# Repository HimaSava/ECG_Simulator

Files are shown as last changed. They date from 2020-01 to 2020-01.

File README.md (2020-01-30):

# ECG_Simulator

This project was part of my Winter Internship 2018 at Streben Healthcare Pvt. Ltd.

### Objective
To create an bluetooth enabled ECG simulator that can mimic the existing system and can trasfer the data without the need for an human subject to be connected to it.

The system should be compact and can replace the existing ECG simulators that are bulky and a hassel to carry around as well as to connect with the software physically.

### A bit about the system:
This ECG simulator was made to mimic the ECG data input from an standard ECG machine. And so the communication protocol is being followed as per the standard. 

Other than that this project is a basic Bluetooth enabled Arduino shield project. The multiple ECG datas are stored on the Arduino and the user can choose between them from the on the board switchs. 

The whole system is conpact and can be easily use a standard mobile powerbank as a power source making it very trasportable.

#### This project was coded and executed by using the following softwares:
* CodeBlocks (C++)
* Arduino IDE (C++)
* Termite (Serial Debugging)
* Eagle 7.6.0 (PCB Designing)

### Contents of the Repository
1. A complete PCB Design with the gerber files aready created.
2. A small C++ application to run on the computer for debugging the data transfer from the Device using bluetooth or USB.
3. The final Arduino code with the preprogrammed ECG Data.
4. Few images of the schematic and final board and PCB Designs.
5. A final Internship Report for the Project.

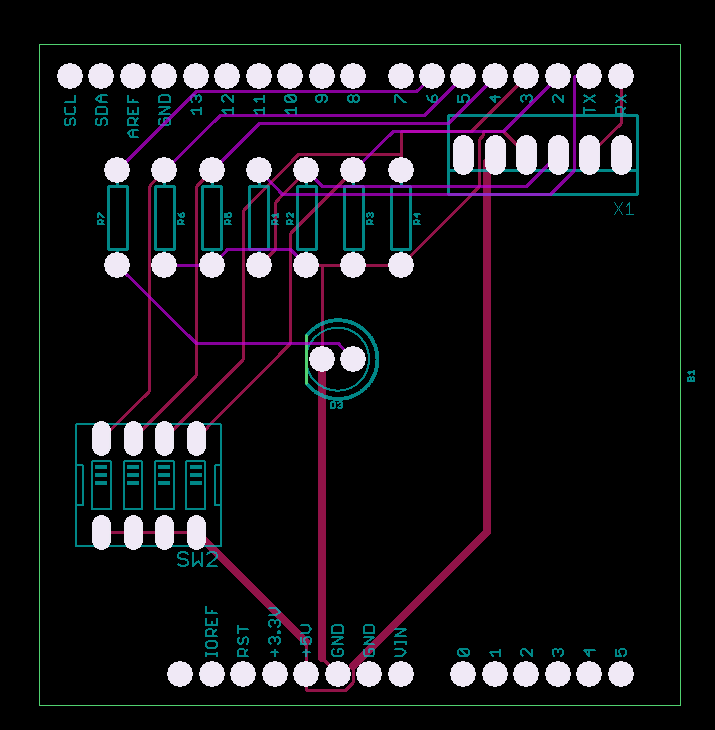
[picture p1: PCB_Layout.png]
PCB Layout


Final Device

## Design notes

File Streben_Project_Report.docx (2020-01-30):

ECG SIMULATOR

PROJECT REPORT

FOR- STREBEN HEALTHCARE PVT. LTD.

BY- HIMANSHU SAVARGAONKAR

INTRODUCTION

ECG(Electro-CardioGram) is one of the most vital measurement techniques when it comes to quantizing the health. It is used in many cases ranging from diagnosing heart diseases, critical surgeries to detecting of stress levels. Though ECG is one of the primary tools acquiring ECG data from a patent is a painstaking process, in which the patient has to be connected with 10 connectors on various parts of the body. These are then connected with the device to acquire the graph. This is very uncomfortable for testing reasons and for demonstrations. Thus, normally the human is replaced by an ECG Simulator for demonstration and development. The simulator is designed in a manner that mimics the human data helping software developers test their applications without physically connecting the leads to a human. Another advantage of a simulator is that the incoming ECG signal can be changed to different types as desired by the user, along with this it is normally quite compact and easy to store. ECG simulators are also used for the endurance test of software’s were the program runs for a long time at a time.

OBJECTIVES

- Development of an ECG simulator which is compatible with the current software.
- The ECG should be wireless and should be able to connect to the software via bluetooth connection.
- The device should give the user option to select from the various sample ECG’s stored on the device.
- The device should be concise with independent battery for easy transport.

SYTEM DESIGN /BLOCK DIAGRAM

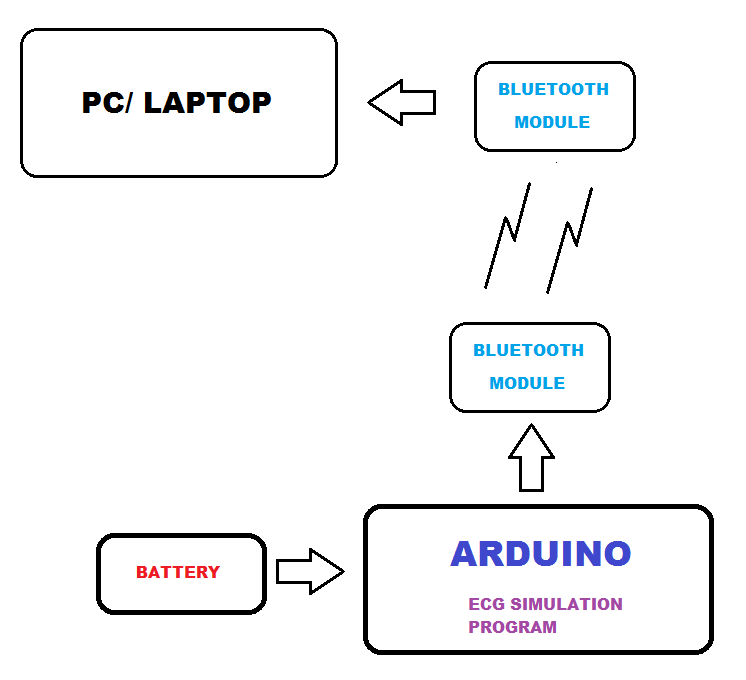
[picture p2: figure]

HARDWARE SUB SYSTEM

The project is based around main two hardware components. Arduino Uno microcontroller board and a HC-05 bluetooth module. The Uno board with AT Mega microcontroller houses the main code and the data of the ECG wave form. It is also responsible for proper compression and packetization of the data. The packetized data then is sent to the bluetooth module via SESRIAL COMMUNICARION PORT WITH Rx and Tx USING RS232 PROTOCOL. The bluetooth module then is connected to the computer running the software where it receives the data.

The device was provided with a dip switch which lets the user manually decide the ECG waveform from the multiple options on board. The device was also given a separate power-bank connection which made the independent AND PORTABLE. An on-board LED was added for visualization of the heart rate of the simulated patient.

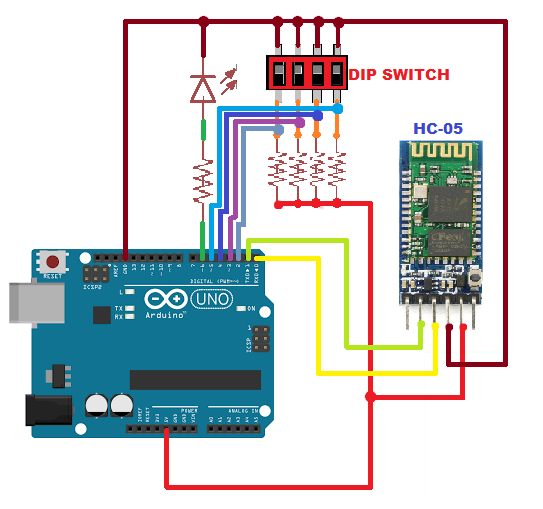
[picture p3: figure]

CIRCUIT DIAGRAM

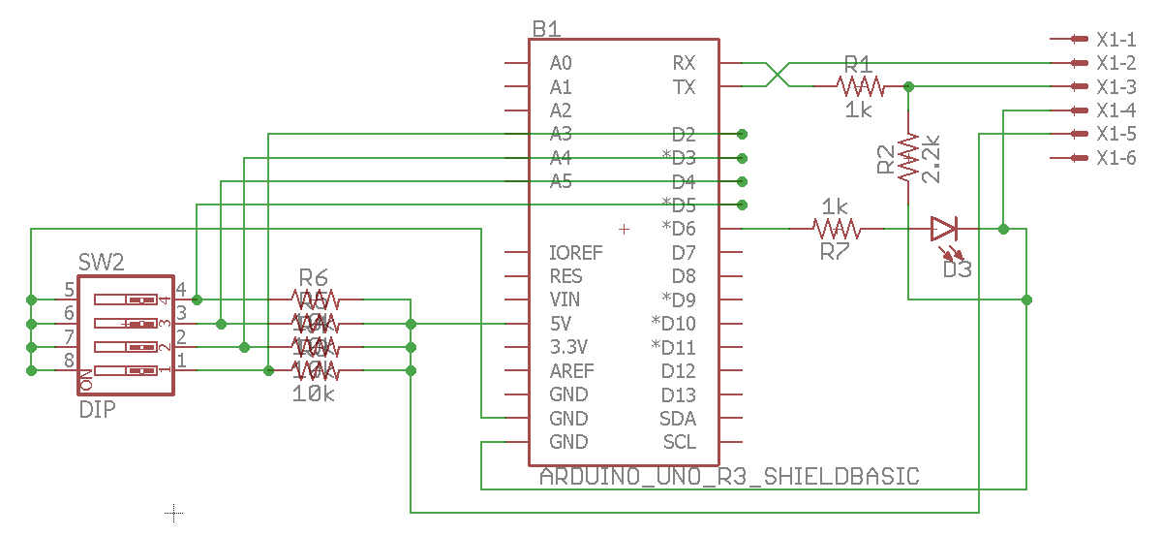
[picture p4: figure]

PCB SCHEMATIC

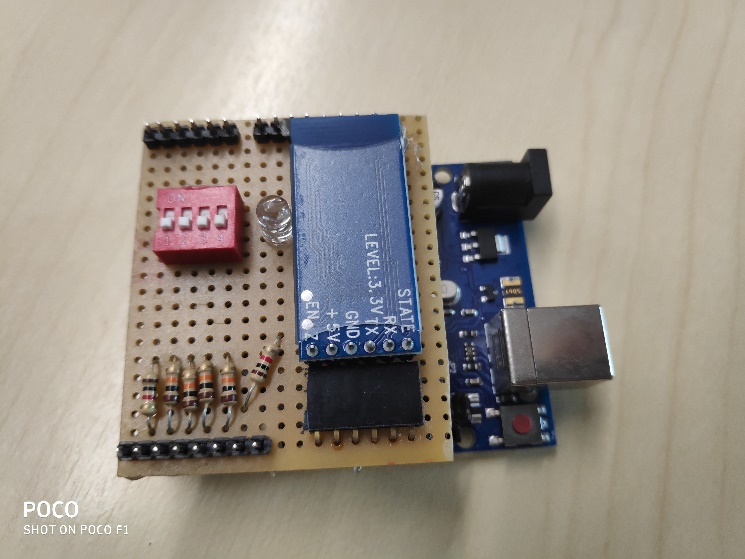
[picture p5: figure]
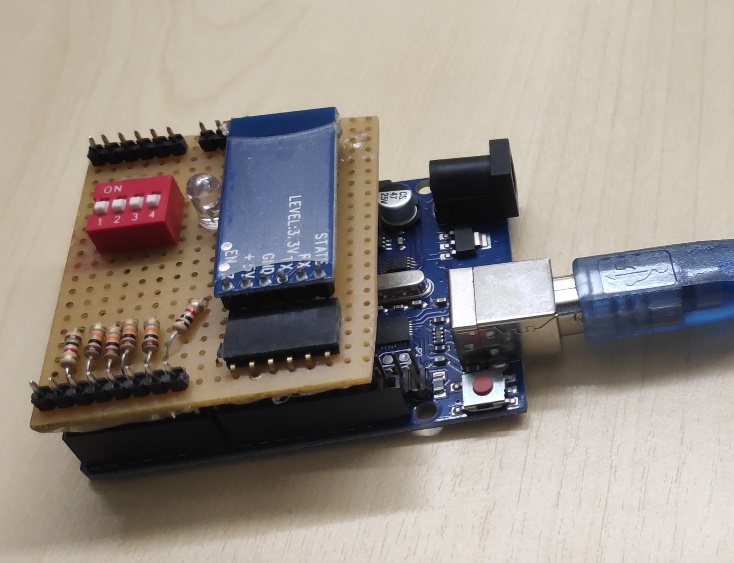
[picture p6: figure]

THE DEVICE

SOFTWARE SUB SYSTEM

There are two main software components to the project.

1. The Arduino Code: This comprises of the code uploaded to the device which outputs the ECG data. Various ECG data is stored in arrays which can then be selected by the switches provided to the user. Once the data array is selected, it undergoes compression and packetization to mimic the ECG data received from the existing device. Once packetized, the data is sent to the computer THROUGH BLUETOOTH MODULE. The transfer of THE data follows the RS232 protocol.
2. The Test App: The main aim of the test app was to have a platform on the computer end to troubleshoot any problems faced in the data transfer process. It comprised of a simple console application that could connect to the bluetooth module and accept and decompress the data. This was used as an intermediate step before integrating the new simulator with the existing software.

FUTURE PLAN

- A custom PCB can be manufactured as an Arduino Uno shield to house all the components. An Arduino Shield is a PCB designed to fit perfectly over the arduino pin outs.
- An enclosure could be designed to house the arduino, the pcb and the battery, making the set up more portable and less delicate.

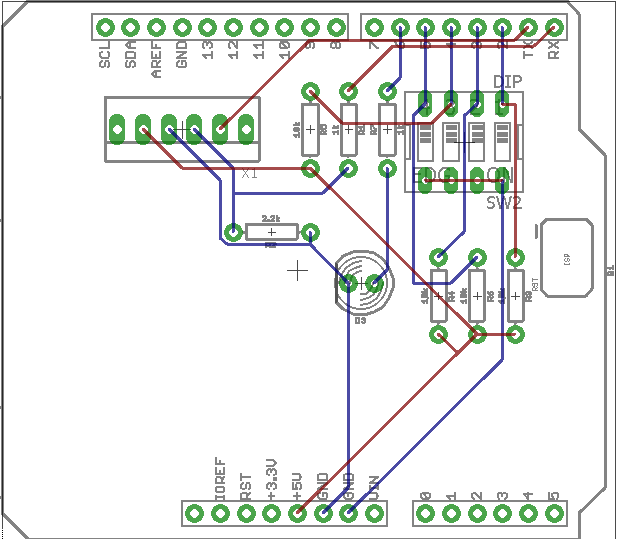
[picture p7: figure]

PCB ARDUINO SHIELD PROTOTYPE

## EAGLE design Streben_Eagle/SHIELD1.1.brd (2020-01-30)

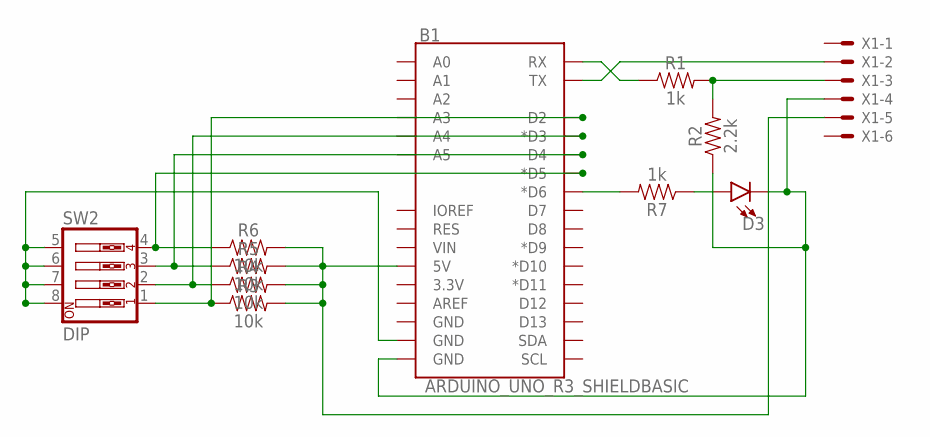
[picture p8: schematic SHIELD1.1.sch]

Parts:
B1: ARDUINO_UNO_R3_SHIELDBASIC; UNO_R3_SHIELD
D3: LED5MM; LED_5MM
R1, R7: 1k; AXIAL-0.3
R2: 2.2k; AXIAL-0.3
R3, R4, R5, R6: 10k; AXIAL-0.3
SW2: DIP; EDG-04
X1: 22-23-2061

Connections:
5V: B1.GND@1 (GND), SW2.5, SW2.6, SW2.7, SW2.8
D2: B1.D2, R3.P$1 (1), SW2.1
D3: B1.D3 (*D3), R4.P$1 (1), SW2.2
GND: B1.GND@0 (GND), D3.K (C), R2.P$1 (1), X1.4
LED: D3.A, R7.P$1 (1)
unnamed: B1.D5 (*D5), R6.P$1 (1), SW2.4
unnamed: B1.RX, R1.P$1 (1)
unnamed: B1.D4, R5.P$1 (1), SW2.3
unnamed: B1.TX, X1.2
unnamed: R1.P$2 (2), R2.P$2 (2), X1.3
unnamed: B1.5V, R3.P$2 (2), R4.P$2 (2), R5.P$2 (2), R6.P$2 (2), X1.5
unnamed: B1.D6 (*D6), R7.P$2 (2)

Board: 2 copper layers, 11 parts (0 on the bottom side), 12 nets, no tracks yet.

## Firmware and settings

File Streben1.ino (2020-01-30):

#include<stdlib.h>
#include<TimerOne.h>

int data[500]={-77,-72,-71,-67,-64,-59,-54,-54,-57,-62,-67,-71,-77,-82,-86,-87,-86,-82,-83,-82,-78,-76,-74,-70,-66,-63,-61,-60,-61,-59,-57,-54,-50,-48,-45,-45,-44,-40,-38,-38,-36,-34,-31,-30,-28,-25,-21,-16,-13,-8,-3,-1,0,0,3,5,7,9,11,15,18,23,28,35,41,45,49,53,57,61,64,65,66,66,67,65,61,60,57,54,53,49,45,43,41,39,39,36,28,20,15,9,1,-2,-6,-12,-17,-21,-27,-30,-33,-36,-38,-40,-41,-43,-43,-47,-47,-47,-50,-55,-60,-62,-64,-66,-66,-69,-69,-69,-68,-68,-65,-63,-60,-59,-58,-56,-56,-55,-54,-54,-53,-54,-54,-53,-54,-57,-59,-60,-61,-63,-63,-64,-65,-66,-68,-71,-70,-67,-64,-65,-64,-65,-64,-65,-65,-66,-67,-67,-67,-66,-64,-60,-59,-58,-58,-55,-53,-52,-52,-54,-56,-57,-59,-58,-55,-54,-53,-53,-57,-62,-62,-60,-60,-60,-61,-63,-64,-66,-69,-69,-69,-67,-67,-66,-65,-66,-63,-61,-57,-52,-53,-52,-53,-54,-54,-55,-53,-51,-51,-52,-52,-51,-51,-51,-54,-56,-60,-59,-60,-60,-57,-54,-51,-50,-48,-49,-48,-45,-46,-46,-49,-52,-55,-55,-57,-60,-62,-62,-65,-66,-65,-66,-66,-63,-61,-62,-61,-62,-62,-59,-56,-53,-53,-56,-57,-59,-58,-56,-56,-55,-53,-50,-47,-45,-43,-46,-48,-50,-54,-61,-65,-66,-67,-64,-61,-59,-57,-53,-48,-46,-46,-47,-51,-54,-57,-61,-64,-66,-67,-67,-62,-62,-63,-60,-58,-56,-55,-53,-52,-51,-48,-45,-41,-41,-45,-48,-50,-54,-57,-58,-58,-61,-64,-64,-65,-62,-58,-57,-55,-58,-59,-60,-62,-63,-65,-68,-66,-65,-66,-63,-61,-58,-57,-57,-56,-56,-56,-57,-60,-61,-63,-63,-61,-60,-58,-57,-55,-56,-55,-54,-55,-54,-54,-53,-51,-50,-47,-44,-41,-39,-36,-37,-37,-38,-41,-45,-50,-54,-58,-59,-61,-62,-62,-60,-58,-54,-49,-44,-40,-35,-29,-25,-24,-23,-26,-29,-29,-29,-30,-29,-27,-26,-21,-16,-13,-12,-10,-10,-8,-8,-9,-9,-8,-7,-7,-3,-2,-5,-8,-11,-15,-21,-26,-32,-37,-41,-42,-44,-44,-45,-45,-45,-46,-47,-49,-48,-49,-52,-52,-51,-53,-54,-53,-52,-48,-46,-47,-48,-51,-53,-55,-56,-55,-56,-57,-59,-62,-63,-63,-63,-63,-64,-65,-64,-62,-60,-56,-49,-35,-19,5,33,63,93,121,152,175,190,196,195,187,176,159,139,114,93,73,57,47,40,33,27,18,11,3,-2,-9,-14,-17,-20,-22,-25,-27,-25,-23,-22,-25,-31};
int pointer=0, i, j, packet[10],a=0,byt[5]={0,0,0,0,0};
int temp[10];
void setup() {
  
  Timer1.initialize(20000); //Half Sec.
  Timer1.attachInterrupt(send_data);
  Serial.begin(115200);
}
int light=0;
void send_data(void)
{
//  byt=0;
  if(pointer==500)
    pointer=0;
  
  for(i=0;i<10;i++)
  {
    temp[i]=data[pointer++];    
  }
  packet[0]=temp[0];
  for(j=1;j<10;j++)
  {
    packet[j]=temp[j-1]-temp[j];
  }
  Serial.write(0x80);
  //Serial.println(byt);
  Serial.write(temp[0] & 0xFF);
  Serial.write(temp[0]>>8);
  for(i=0;i<22;i++)
    Serial.print(a);
  //Serial.println(byt);
  for(i=1;i<10;i++)
  {
    Serial.write(temp[i]);
    for(j=0;j<11;j++)
    {
      Serial.print(a);
    }
  }
   
}

void loop()
{
  if(light==1)
  {
    digitalWrite(13,LOW);
    light=0;
  }
  else
  {
    digitalWrite(13,HIGH);
    light=1;
  }
  delay(1000);
}

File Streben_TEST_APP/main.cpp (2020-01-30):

/*******************************************************
 *File name: main.cpp
 *
 *Description: This is the test app created for the ECG
 *             Simulator made by Himanshu S.
 *
 ******************************************************/

#include<windows.h>
#include<stdio.h>
#include<string.h>
#include<iostream>
#include<fstream>

#define FILE_MENU_START     1
#define FILE_MENU_EXIT      2
#define COM_5               3
#define COM_6               4
#define COM_7               5
#define COM_8               6


LRESULT CALLBACK WndProc(HWND,UINT,WPARAM,LPARAM);
void AddMenu(HWND);
void SerialConnect();
void StartECG();
void decode(char[]);
void RecordECG(int[]);

HMENU hMenu;
DWORD dwEventMask;
HANDLE hComm;
HANDLE hECGData;
HWND hWnd;
char ComPortName[5];


int WINAPI WinMain (HINSTANCE hInst,HINSTANCE hPrevInst,LPSTR args,int ncmdshow)
{
    WNDCLASSW                   wc = {0};

    MSG                         msg = {0};

    wc.hbrBackground = (HBRUSH)COLOR_WINDOW ;
    wc.hCursor = LoadCursor(NULL,IDC_ARROW);
    wc.hInstance = hInst;
    wc.lpszClassName = L"TEST_APP";
    wc.lpfnWndProc = WndProc;

    if(!RegisterClassW(&wc))
        return(-1);

    hWnd = CreateWindow((LPCSTR)"TEST_APP",(LPCSTR)"TEST_APP",WS_OVERLAPPEDWINDOW | WS_VISIBLE,500,500,200,200,NULL,NULL,NULL,NULL);

    ShowWindow(hWnd,ncmdshow);
    UpdateWindow(hWnd);


    while(GetMessage(&msg,NULL,NULL,NULL))
    {
        TranslateMessage(&msg);
        DispatchMessage(&msg);
    }
    return 0;
}

LRESULT CALLBACK WndProc(HWND hWnd,UINT msg,WPARAM wp,LPARAM lp)
{

    switch(msg)
    {
    case WM_COMMAND:

        switch(wp)
        {
        case FILE_MENU_START:
            MessageBeep(MB_OK);
            StartECG();
            break;
        case FILE_MENU_EXIT:
            MessageBeep(MB_OK);
            DestroyWindow(hWnd);
            break;
        case COM_5:
            strcpy(ComPortName,"COM5");
            SerialConnect();
            break;
        case COM_6:
            strcpy(ComPortName,"COM6");
            SerialConnect();
            break;
        case COM_7:
            strcpy(ComPortName,"COM7");
            SerialConnect();
            break;
        case COM_8:
            strcpy(ComPortName,"COM8");
            SerialConnect();
            break;
        }
        break;
    case WM_CREATE:
        AddMenu(hWnd);
        break;
    case WM_DESTROY:
        PostQuitMessage(0);
        break;
    default:
            return DefWindowProcW(hWnd,msg,wp,lp);
    }
}

void AddMenu(HWND hWnd)
{
    hMenu= CreateMenu();
    HMENU hFileMenu = CreateMenu();
    HMENU hComPort = CreateMenu();
    AppendMenu(hMenu,MF_POPUP,(UINT_PTR)hFileMenu,(LPCSTR)"File");
        AppendMenu(hFileMenu,MF_POPUP,(UINT_PTR)hComPort,(LPCSTR)"COM");
            AppendMenu(hComPort,MF_STRING,COM_5,(LPCSTR)"COM5");
            AppendMenu(hComPort,MF_STRING,COM_6,(LPCSTR)"COM6");
            AppendMenu(hComPort,MF_STRING,COM_7,(LPCSTR)"COM7");
            AppendMenu(hComPort,MF_STRING,COM_8,(LPCSTR)"COM8");
        AppendMenu(hFileMenu,MF_STRING,FILE_MENU_START,(LPCSTR)"Start");
        AppendMenu(hFileMenu,MF_SEPARATOR,NULL,NULL); // This statement adds a line between the menu components above and below the stat.
        AppendMenu(hFileMenu,MF_STRING,FILE_MENU_EXIT,(LPCSTR)"Exit");
    AppendMenu(hMenu,MF_STRING,2,(LPCSTR)"Help");
    SetMenu(hWnd,hMenu);
}

void SerialConnect()
{
	BOOL  Status;

	int i = 0;
	hComm = CreateFile( ComPortName,
		    GENERIC_READ | GENERIC_WRITE,
            0,
			NULL,
			OPEN_EXISTING,
		    0,
		    NULL);


			/*------------------------------- Setting the Parameters for the SerialPort ------------------------------*/

	DCB dcbSerialParams = { 0 };                         // Initializing DCB structure
	dcbSerialParams.DCBlength = sizeof(dcbSerialParams);

	Status = GetCommState(hComm, &dcbSerialParams);      //retreives  the current settings

	if (Status == FALSE)
    {
        MessageBox(hWnd,(LPCSTR)"ERROR OPENING!!",(LPCSTR)"COM PORT",MB_OK);
	}

	dcbSerialParams.BaudRate = CBR_115200;      // Setting BaudRate = 115200
	dcbSerialParams.ByteSize = 8;             // Setting ByteSize = 8
	dcbSerialParams.StopBits = ONESTOPBIT;    // Setting StopBits = 1
	dcbSerialParams.Parity = NOPARITY;        // Setting Parity = None

	Status = SetCommState(hComm, &dcbSerialParams);  //Configuring the port according to settings in DCB

	if (Status == FALSE)
	{
        MessageBox(hWnd,(LPCSTR)"ERROR OPENING!!",(LPCSTR)"COM PORT",MB_OK);
	}

			/*------------------------------------ Setting Timeouts --------------------------------------------------*/

	COMMTIMEOUTS timeouts = { 0 };
	timeouts.ReadIntervalTimeout         = 50;
	timeouts.ReadTotalTimeoutConstant    = 50;
	timeouts.ReadTotalTimeoutMultiplier  = 10;
	timeouts.WriteTotalTimeoutConstant   = 50;
	timeouts.WriteTotalTimeoutMultiplier = 10;

	if (SetCommTimeouts(hComm, &timeouts) == FALSE)
	{
        MessageBox(hWnd,(LPCSTR)"ERROR OPENING!!",(LPCSTR)"COM PORT",MB_OK);
	}

			/*------------------------------------ Setting Receive Mask ----------------------------------------------*/

	Status = SetCommMask(hComm, EV_RXCHAR); //Configure Windows to Monitor the serial device for Character Reception

	if (Status == FALSE)
    {
        MessageBox(hWnd,(LPCSTR)"ERROR OPENING!!",(LPCSTR)"COM PORT",MB_OK);
    }
    else
    {
        MessageBox(hWnd,(LPCSTR)"PORT OPENED SUCCESSFULLY",(LPCSTR)"COM PORT",MB_OK);
    }


           /*------------------------------------ Setting WaitComm() Event   ----------------------------------------*/

}

void StartECG()
{
    int flag, flag2, i;
    char        Temp;
    char        SerialBuffer[255];
    DWORD       NoBytesRead;
    char Name[] = "ECG.txt";
    WaitCommEvent(hComm, &dwEventMask, NULL); //Wait for the character to be received
    flag = 0;
    hECGData = CreateFile(Name,GENERIC_READ | GENERIC_WRITE,0,NULL,CREATE_ALWAYS,0,NULL);
	while(flag!=100)
    {

        SerialBuffer[0]='/0';
		i=0;
		ReadFile(hComm, &Temp, sizeof(Temp), &NoBytesRead, NULL);
		if((int)Temp==-128)
        {
            flag++;
            do
            {
                ReadFile(hComm, &Temp, sizeof(Temp), &NoBytesRead, NULL);
                if( NoBytesRead >= 1)
                {
                    SerialBuffer[i] = Temp;
                    i++;
                }
            }
            while (i!=132);
            decode(SerialBuffer);
        }
    }
    CloseHandle(hComm);//Closing the Serial Port
    CloseHandle(hECGData);
}
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

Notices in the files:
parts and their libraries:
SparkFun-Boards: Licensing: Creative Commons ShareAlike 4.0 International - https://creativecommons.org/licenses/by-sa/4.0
